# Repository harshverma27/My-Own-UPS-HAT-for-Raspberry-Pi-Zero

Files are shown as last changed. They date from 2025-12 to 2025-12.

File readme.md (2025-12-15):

# 🔋 Raspberry Pi Zero 2 UPS (TP4056 + DW01A + TPS61236)

## 📌 Overview

This project is a **budget-friendly UPS (Uninterruptible Power Supply)** designed specifically for the **Raspberry Pi Zero 2**.

I built this because I personally use a **Pi Zero 2**, and I needed a **reliable battery backup (UPS)** for it.
Most ready-made UPS solutions available are either:

* Too expensive
* Overkill for Pi Zero
* Poorly designed or unreliable

So instead of buying one, **I designed my own UPS PCB from scratch**.

This design uses **commonly available and low-cost ICs** while still following **proper battery safety and power design practices**.

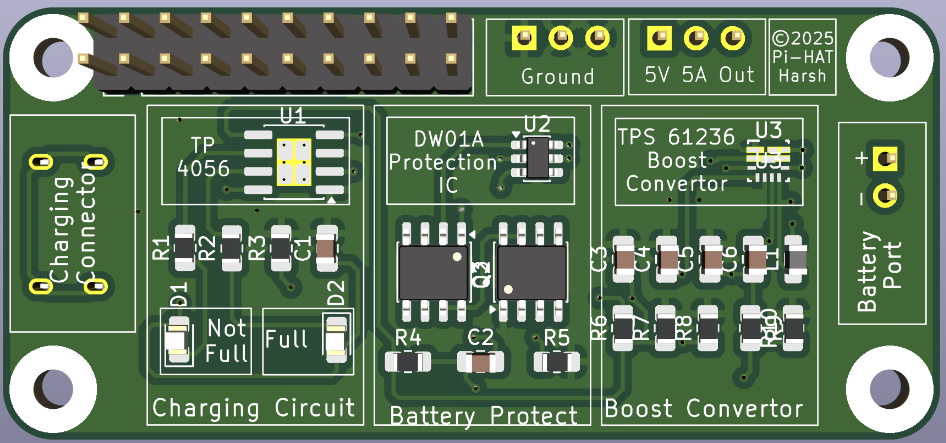
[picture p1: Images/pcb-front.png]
pcb-front

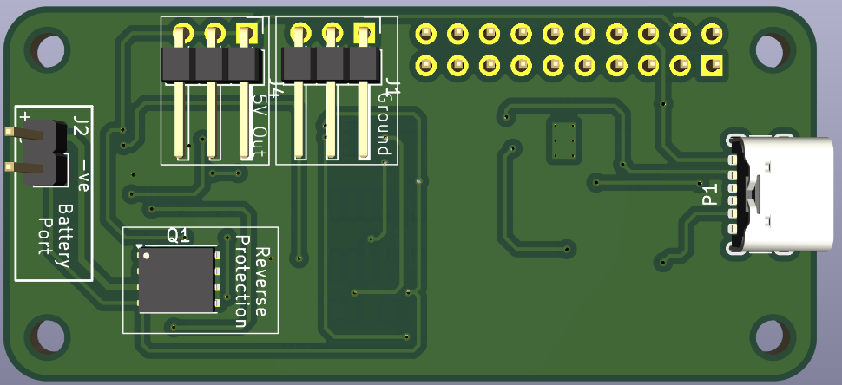
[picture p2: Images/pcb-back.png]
pcb-back


---

## 🧩 Project Architecture

The PCB is divided into **three main functional blocks**:

1. **Battery Protection Circuit**
2. **Battery Charging Circuit**
3. **Boost Converter (5V Output for Raspberry Pi)**

Each block is electrically separated but works together as a complete system.

---

## 🔋 1. Battery Protection (DW01A + MOSFETs)

Lithium-ion batteries must **never** be:

* Over-discharged
* Over-charged
* Short-circuited

To ensure safety, this design uses the **DW01A battery protection IC** along with external MOSFETs.

### What this block does:

* Cuts off the load if battery voltage drops too low (low-voltage cutoff)
* Protects against over-current and short-circuit
* Protects the battery during charging and discharging

This ensures the 18650 cell is always operating within safe limits.

---

## 🔌 2. Battery Charging Circuit (TP4056)

Charging is handled by the **TP4056**, a popular and reliable **single-cell Li-ion charger IC**.

### Why TP4056:

* Simple linear charger
* Constant Current / Constant Voltage (CC/CV) charging
* Reliable and widely used
* Easy to configure charging current

### Important design choice:

The **TP4056 is used only for charging**.
It does **not power the load directly**.

The battery is always protected by the **DW01A**, and the charger connects safely through the protection circuit.

---

## ⚡ 3. Boost Converter (TPS61236)

The Raspberry Pi Zero 2 requires a **stable 5V supply**.

Since a single 18650 battery provides **3.0V–4.2V**, a boost converter is required.

This project uses the **TPS61236** boost converter.

### What this block does:

* Boosts battery voltage to a stable **5V**
* Provides enough current for Raspberry Pi Zero 2
* Designed with proper layout considerations for efficiency and stability

The boost converter draws power **only through the protected battery path**, ensuring the battery is never over-discharged.

---

## 🔁 How Everything Works Together

1. **Battery powers the system** through the protection circuit
2. **Boost converter generates 5V** for Raspberry Pi Zero 2
3. **TP4056 charges the battery** when external power is available
4. If external power is removed:

   * Battery instantly takes over
   * Pi continues running without reboot
5. If battery voltage becomes too low:

   * DW01A disconnects the load to protect the battery

This makes the system act like a **true UPS**.

---

## 🎯 Why I Built This Project

* I own a **Raspberry Pi Zero 2**
* I needed a **low-cost, reliable UPS**
* Commercial solutions were expensive or poorly suited
* I wanted:

  * Battery safety
  * Proper power design
  * Full control over the hardware
* This project was also a **learning experience in power electronics and PCB design**

---

## 🛠️ Features

* Li-ion battery support (3.7V)
* Battery protection (LVC, OCP, SCP)
* Safe and reliable charging
* 5V regulated output for Raspberry Pi Zero 2
* Budget-friendly and open-source
* Designed as a **PCB**, not a breadboard hack

---

## 📂 Repository Contents

* `Kicad Projtect/` – Full Kicad Projtect
* `gerbers/` – Manufacturing-ready files
* `README.md` – Project documentation

---

## ⚠️ Disclaimer

This project involves **lithium-ion batteries**.
Improper handling or incorrect assembly can cause damage or injury.

Build and use at your own risk.
Always verify connections before inserting a battery.

---

## ⭐ Future Improvements

* Battery percentage monitoring
* Load current measurement
* Power-fail detection GPIO for Raspberry Pi
* Multiple-cell support

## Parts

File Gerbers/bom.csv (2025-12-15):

Designator | Footprint | Quantity | Value | LCSC Part #
C1 | 0805 | 1 | 10uF
C2 | 0805 | 1 | 0.1uF
C3 | 0805 | 1 | 10uF 5.787mOhm
C4 | 0805 | 1 | 10nF 1mOhm
C5 | 0805 | 1 | 47uF
C6 | 0805 | 1 | 10pF
D1 | 0805 | 1 | LED (RED)
D2 | 0805 | 1 | LED (GREEN)
J1, J4 | PinHeader_1x03_P2.54mm_Horizontal | 2 | Conn_01x03_Pin
J2 | PinHeader_1x02_P2.54mm_Vertical | 1 | Conn_01x02_Pin
J5 | PinHeader_2x10_P2.54mm_Vertical | 1 | Conn_02x10_Odd_Even
L1 | 0805 | 1 | 1uH 10mOhm
P1 | USB_C_Receptacle_GCT_USB4125-xx-x_6P_TopMnt_Horizontal | 1 | USB_C_Plug_USB2.0
Q1 | TDSON-8-1 | 1 | FDMS86350
Q2, Q3 | SOIC-8_3.9x4.9mm_P1.27mm | 2 | AO4842
R1, R2 | 0805 | 2 | 1k
R10 | 0805 | 1 | 205k Ohm
R3 | 0805 | 1 | 2k
R4 | 0805 | 1 | 100 ohm
R5 | 0805 | 1 | 1k ohm
R6, R7 | 0805 | 2 | 1M Ohm
R8 | 0805 | 1 | 30.9k Ohm
R9 | 0805 | 1 | 619k Ohm
U1 | SOIC-8-1EP_3.9x4.9mm_P1.27mm_EP2.41x3.3mm_ThermalVias | 1 | TP4056-42-ESOP8
U2 | SOT-23-6 | 1 | DW01A
U3 | RWL0009A | 1 | TPS61236PRWLR

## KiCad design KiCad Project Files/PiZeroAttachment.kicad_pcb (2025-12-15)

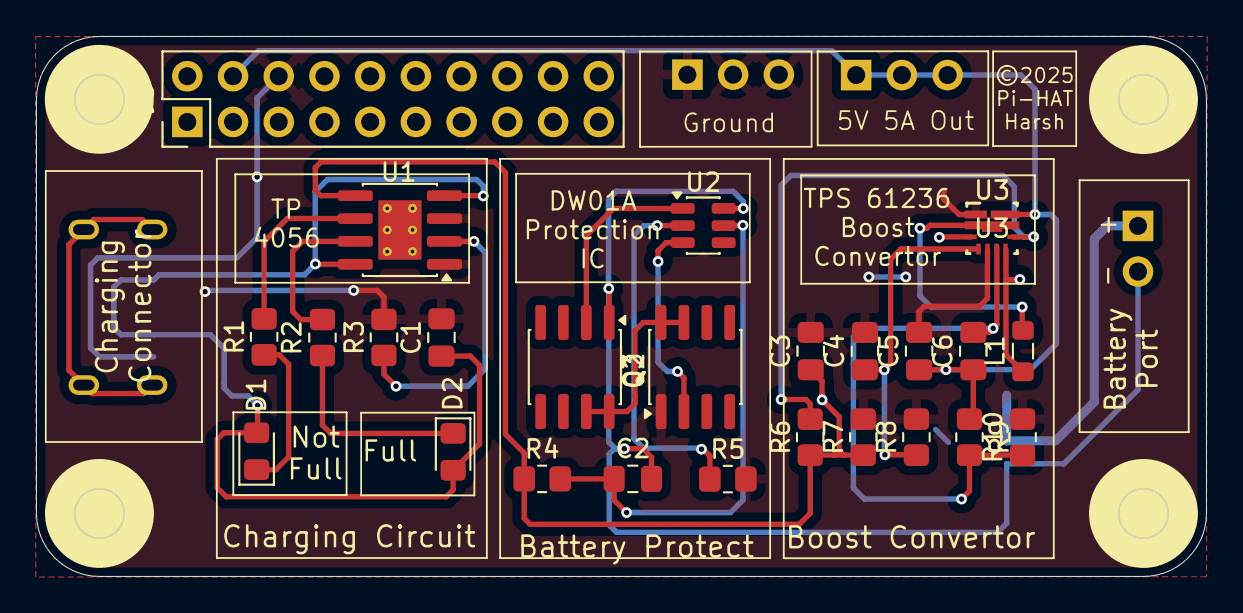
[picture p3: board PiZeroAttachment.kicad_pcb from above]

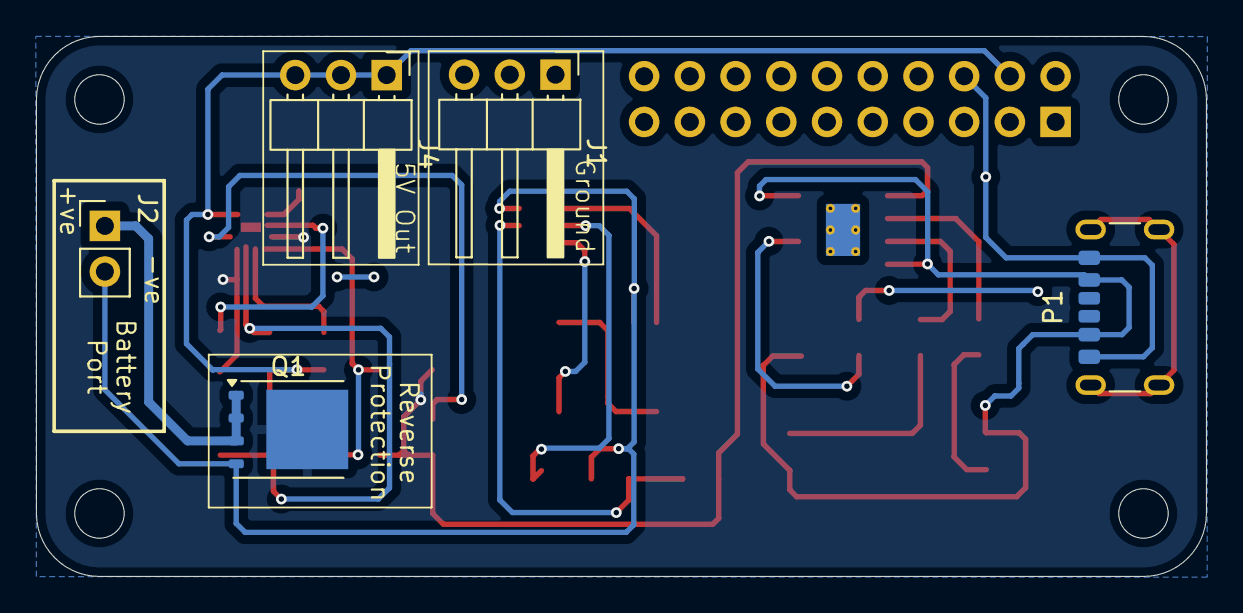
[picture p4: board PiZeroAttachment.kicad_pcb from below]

Board: 2 copper layers, 65.0 x 30.0 mm, 30 parts (5 on the bottom side), 20 nets.

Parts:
C1: 10uF; C_0805_2012Metric_Pad1.18x1.45mm_HandSolder
C2: 0.1uF; C_0805_2012Metric_Pad1.18x1.45mm_HandSolder
C3: 10uF 5.787mOhm; C_0805_2012Metric_Pad1.18x1.45mm_HandSolder
C4: 10nF 1mOhm; C_0805_2012Metric_Pad1.18x1.45mm_HandSolder
C5: 47uF; C_0805_2012Metric_Pad1.18x1.45mm_HandSolder
C6: 10pF; C_0805_2012Metric_Pad1.18x1.45mm_HandSolder
D1: LED (RED); LED_0805_2012Metric_Pad1.15x1.40mm_HandSolder
D2: LED (GREEN); LED_0805_2012Metric_Pad1.15x1.40mm_HandSolder
J1, J4: Conn_01x03_Pin; PinHeader_1x03_P2.54mm_Horizontal
J2: Conn_01x02_Pin; PinHeader_1x02_P2.54mm_Vertical
J5: Conn_02x10_Odd_Even; PinHeader_2x10_P2.54mm_Vertical
L1: 1uH 10mOhm; L_0805_2012Metric_Pad1.05x1.20mm_HandSolder
P1: USB_C_Plug_USB2.0; USB_C_Receptacle_GCT_USB4125-xx-x_6P_TopMnt_Horizontal
Q1: FDMS86350; TDSON-8-1
Q2, Q3: AO4842; SOIC-8_3.9x4.9mm_P1.27mm
R1, R2: 1k; R_0805_2012Metric_Pad1.20x1.40mm_HandSolder
R3: 2k; R_0805_2012Metric_Pad1.20x1.40mm_HandSolder
R4: 100 ohm; R_0805_2012Metric_Pad1.20x1.40mm_HandSolder
R5: 1k ohm; R_0805_2012Metric_Pad1.20x1.40mm_HandSolder
R6, R7: 1M Ohm; R_0805_2012Metric_Pad1.20x1.40mm_HandSolder
R8: 30.9k Ohm; R_0805_2012Metric_Pad1.20x1.40mm_HandSolder
R9: 619k Ohm; R_0805_2012Metric_Pad1.20x1.40mm_HandSolder
R10: 205k Ohm; R_0805_2012Metric_Pad1.20x1.40mm_HandSolder
U1: TP4056-42-ESOP8; SOIC-8-1EP_3.9x4.9mm_P1.27mm_EP2.41x3.3mm_ThermalVias
U2: DW01A; SOT-23-6
U3: TPS61236PRWLR; RWL0009A

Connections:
5V+: C5.1, C6.1, J4.1, J4.2, J4.3, J5.4, R9.1, U3.9 (VOUT)
5V-: C1.2, C3.2, C4.2, C5.2, J1.1, J1.2, J1.3, J5.6, P1.A12 (GND), P1.B12 (GND), Q3.1 (S1), R3.2, R5.2, R7.2, R8.2, R10.2, U1.1 (TEMP), U1.3 (GND), U3.1 (PGND), U3.5 (AGND)
BAT+: C3.1, L1.1, Q1.5 (D), R4.1, R6.1, R7.1, U1.5 (BAT), U3.3 (VIN), U3.7 (EN)
BAT-: C2.2, J2.2, Q1.4 (G), Q2.1 (S1), U2.6 (GND)
unnamed: C1.1, D1.2 (A), D2.2 (A), P1.A9 (VBUS), P1.B9 (VBUS), U1.4 (V_{CC}), U1.8 (CE)
unnamed: D1.1 (K), R1.1
unnamed: D2.1 (K), R2.1
unnamed: J2.1, Q1.1 (S), Q1.2 (S), Q1.3 (S)
unnamed: Q2.7 (D1), Q2.8 (D1), Q3.7 (D1), Q3.8 (D1)
unnamed: Q2.2 (G1), U2.1 (OD)
unnamed: Q3.2 (G1), U2.3 (OC)
unnamed: R3.1, U1.2 (PROG)
unnamed: R2.2, U1.7 (~CHRG)
unnamed: R1.2, U1.6 (~STDBY)
unnamed: R5.1, U2.2 (CS)
unnamed: C2.1, R4.2, U2.5 (VCC)
unnamed: C4.1, R8.1, U3.4 (CC)
unnamed: C6.2, R9.2, R10.1, U3.6 (FB)
unnamed: R6.2, U3.8 (INACT)
unnamed: L1.2, U3.2 (SW)

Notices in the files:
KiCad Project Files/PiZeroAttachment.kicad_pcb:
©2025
